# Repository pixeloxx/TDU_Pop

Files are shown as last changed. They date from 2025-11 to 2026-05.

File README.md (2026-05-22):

## Tactile Pop

A simple oral electro tactile interface based on this [paper by Kurt Kaczmarek](https://www.sciencedirect.com/science/article/pii/S1026309811001702) and some inspiration from Cthulhu Shield by [Sapien LLC](http://sapienllc.com/). 

The basic setup is a shield for the Arduino Mega board, with an edge connector for attaching TDU electrodes. The Tactile Pop itself uses a PCB, so it is not certified for contact with the mouth: please use it at your own risk! The pop should be coated with a food safe resin, leaving the electrodes exposed. Use gold coating on the electrode PCB for a safer surface coating. 

This repository contains firmware, patterns and Eagle project files for the Tactile Pop TDU. 

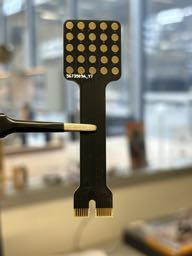
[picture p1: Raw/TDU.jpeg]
Tactile Display Unit (TDU)


Repository layout
----------------
- `Code/` — Arduino sketches and supporting code.
  - `Patterns/` — pattern generator and example patterns (`Patterns.ino`).
  - `Screen/`, `Serial/` — alternative sketches and helpers for serial interface and an attached display. 
- `Electronics/` — Eagle project files and CAM outputs for the controller shield and the the pop TDU pcb. 

Quick start
-----------
1. Open the relevant Arduino sketch from `Code/` in the Arduino IDE .
2. Compile and upload to your compatible microcontroller.
3. Use the `Patterns` sketch or the serial interface to send patterns to the device.

Electrode stimulation 
----------------------

A number of parameters in the pulse patter can be changed, to give a range of intensity and qualities of sensation. Longer pulses will effect Nociceptors (prickly, needle like sensations), while shorter will tend to activate tactile receptors. Some stimulation of taste receptors is also possible.     

The the following parameters can be edited, and fine tuned for each individual electrode. 

PP[] — Pulse Period (microseconds). Total period of one inner pulse (high + low). Unit: µs.
Pp[] — Pulse-on time (microseconds). Time the pin is HIGH during one inner pulse. Unit: µs. 
IN[] — Inner burst count (integer). Number of inner pulses in one inner burst. 
IP[] — Inner burst pause (microseconds). Pause after each inner burst (time between inner bursts). 
ON[] — Outer burst count (integer). Number of inner bursts in one outer burst. 

Sensing Tongue Contact
----------------------

It's possible to sense tongue contact using ADC-capable pins, which is only the first three rows of the TDU. 
 
 ```C#
    const int sensingPins[5][5] = {
      {A1, A2, A3, A4, A5},
      {A6, A7, A8, A9, A10},
      {A11, A12, A13, A14, A15},
      {1, 2, 3, 4, 5},
      {6, 7, 8, 9, 10}
    };
 ```

The example below shows how you can also read a chanel, to check if the tongue is in contact with an electrode.  
 ```C#
    
    int baseLine = 800; 

    bool readSensing(int row, int col) {
      if (row < 0 || row >= 5 || col < 0 || col >= 5) return -1;
      int pin = sensingPins[row][col];
      return analogRead(pin);
        pinMode(pin, OUTPUT);
        digitalWrite(pin, HIGH);
        delayMicroseconds(400);
        pinMode(pin, INPUT);
        int response = analogRead(pin);
        delay(IntensityDelay);
        pinMode(pin, OUTPUT);
        digitalWrite(pin, LOW);
        return (response>baseLine);
    }

 ```

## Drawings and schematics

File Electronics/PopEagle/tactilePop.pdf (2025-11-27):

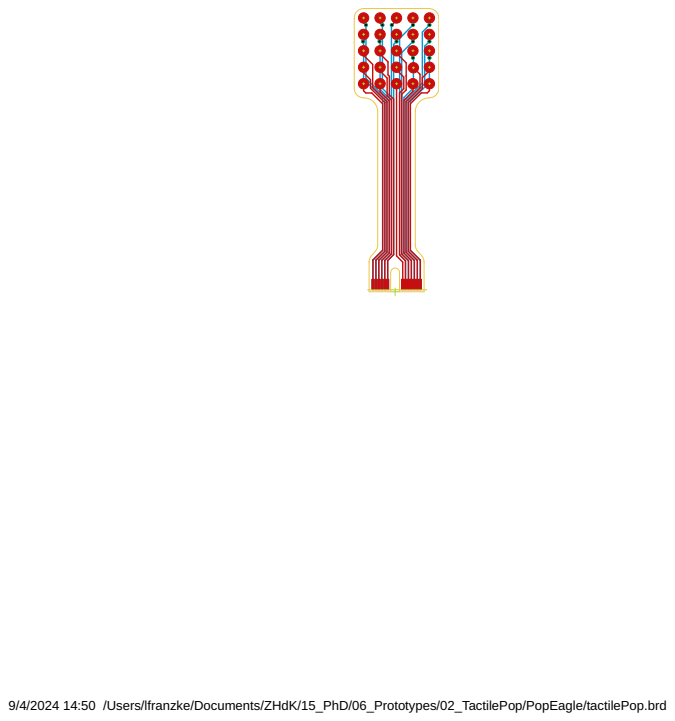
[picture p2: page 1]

9/4/2024 14:50 /Users/lfranzke/Documents/ZHdK/15_PhD/06_Prototypes/02_TactilePop/PopEagle/tactilePop.brd

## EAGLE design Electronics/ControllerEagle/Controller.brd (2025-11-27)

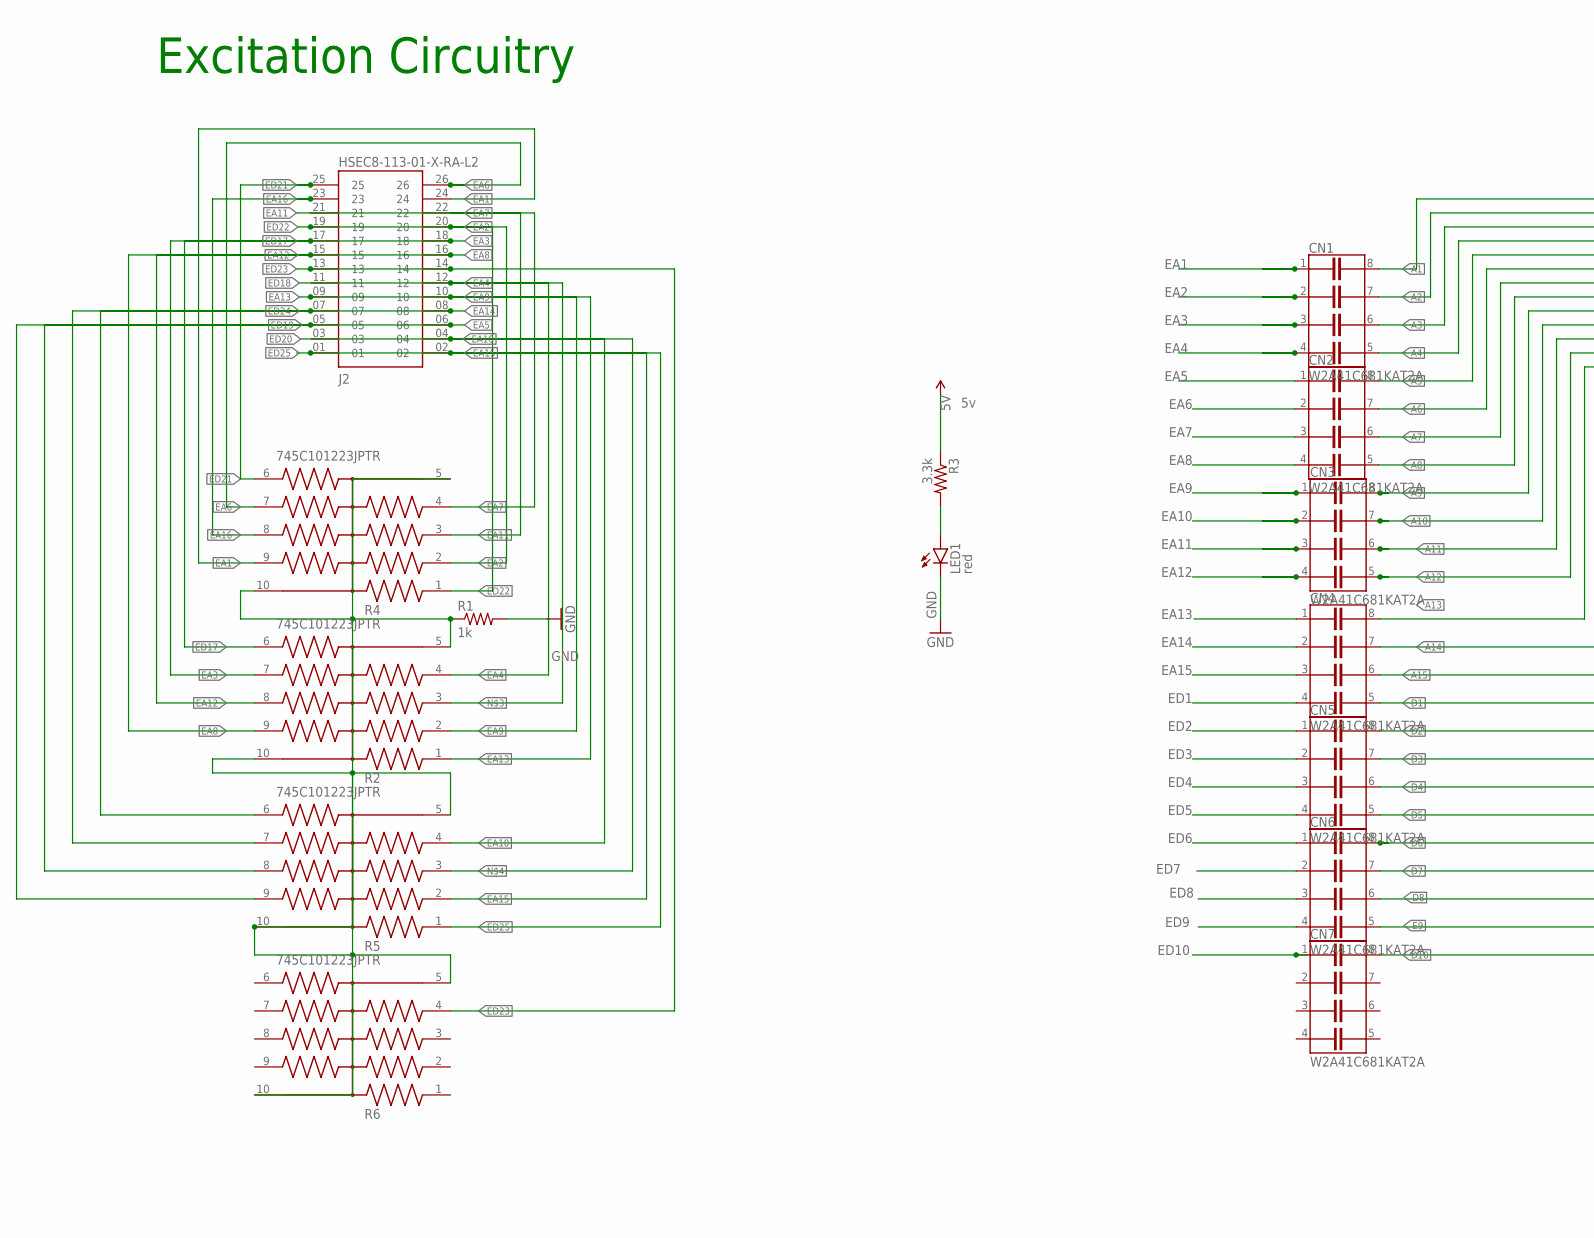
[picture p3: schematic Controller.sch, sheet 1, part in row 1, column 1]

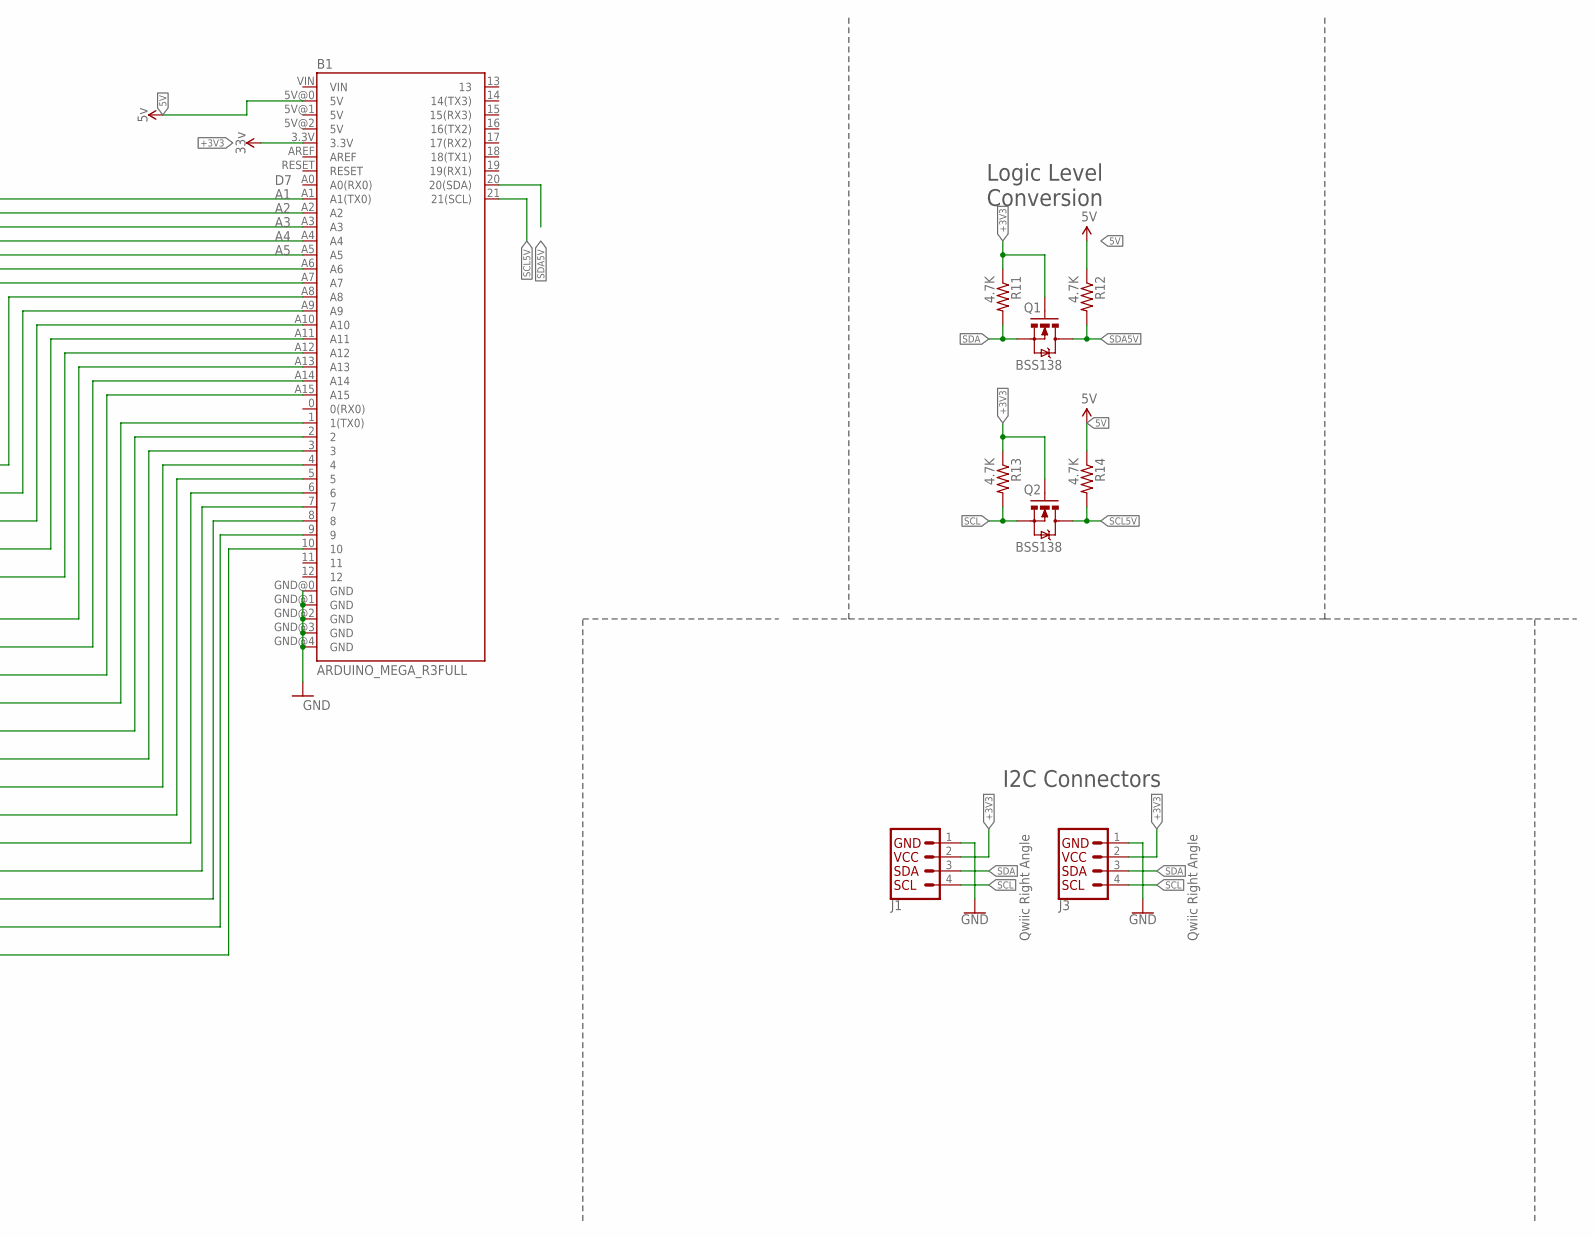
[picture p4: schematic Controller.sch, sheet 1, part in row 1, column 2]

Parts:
B1: ARDUINO_MEGA_R3FULL; ARDUINO_MEGA
CN1, CN2, CN3, CN4, CN5, CN6, CN7: W2A41C681KAT2A; CAPCAXE50P210X130X94-8N
J1, J3: Qwiic Right Angle; 1X04_1MM_RA
J2: HSEC8-113-01-X-RA-L2; SAMTEC_HSEC8-113-01-X-RA-L2
LED1: red; LED-1206
Q1, Q2: BSS138; SOT23-3
R1: 1k; 0402
R2, R4, R5, R6: 745C101223JPTR; RESCAV127P640X310X70-10N
R3: 3.3k; 0402
R11, R12, R13, R14: 4.7K; 0603-RES

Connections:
5V: B1.5V@0 (5V), R3.1, R12.1, R14.1
+3V3: B1.3.3V, J1.2, J3.2, Q1.1 (G), Q2.1 (G), R11.1, R13.1
A1: B1.A1 (A1(TX0)), CN1.8
A2: B1.A2, CN1.7
A3: B1.A3, CN1.6
A4: B1.A4, CN1.5
A5: B1.A5, CN2.8
A6: B1.A6, CN2.7
A7: B1.A7, CN2.6
A8: B1.A8, CN2.5
A9: B1.A9, CN3.8
A10: B1.A10, CN3.7
A11: B1.A11, CN3.6
A12: B1.A12, CN3.5
A13: B1.A13, CN4.8
A14: B1.A14, CN4.7
A15: B1.A15, CN4.6
D1: B1.1 (1(TX0)), CN4.5
D2: B1.2, CN5.8
D3: B1.3, CN5.7
D4: B1.4, CN5.6
D5: B1.5, CN5.5
D6: B1.6, CN6.8
D7: B1.7, CN6.7
D8: B1.8, CN6.6
D10: B1.10, CN7.8
E9: B1.9, CN6.5
EA1: CN1.1, J2.24, R4.9
EA2: CN1.2, J2.20, R4.2
EA3: CN1.3, J2.18, R2.7
EA4: CN1.4, J2.12, R2.4
EA5: CN2.1, J2.06, R5.9
EA6: CN2.2, J2.26, R4.7
EA7: CN2.3, J2.22, R4.4
EA8: CN2.4, J2.16, R2.9
EA9: CN3.1, J2.10, R2.2
EA10: CN3.2, J2.04, R5.4
EA11: CN3.3, J2.21, R4.3
EA12: CN3.4, J2.15, R2.8
EA13: CN4.1, J2.09, R2.1
EA14: CN4.2, J2.08, R5.7
EA15: CN4.3, J2.02, R5.2
EA16: J2.23, R4.8
ED1: CN4.4
ED2: CN5.1
ED3: CN5.2
ED4: CN5.3
ED5: CN5.4
ED6: CN6.1
ED7: CN6.2
ED8: CN6.3
ED9: CN6.4
ED10: CN7.1
ED17: J2.17, R2.6
ED19: J2.05, R5.8
ED21: J2.25, R4.6
ED22: J2.19, R4.1
ED23: J2.13, J2.14, R6.4
ED24: J2.07, R5.6
ED25: J2.01, R5.1
GND: B1.GND@0 (GND), B1.GND@1 (GND), B1.GND@2 (GND), B1.GND@3 (GND), B1.GND@4 (GND), J1.1, J3.1, LED1.C, R1.2
unnamed: LED1.A, R3.2
unnamed: R1.1, R2.5, R2.10, R4.5, R4.10, R5.5, R5.10, R6.5, R6.10
unnamed: J2.11, R2.3
unnamed: J2.03, R5.3
SCL: J1.4, J3.4, Q2.2 (S), R13.2
SCL5V: B1.21 (21(SCL)), Q2.3 (D), R14.2
SDA: J1.3, J3.3, Q1.2 (S), R11.2
SDA5V: B1.20 (20(SDA)), Q1.3 (D), R12.2

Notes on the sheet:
Excitation Circuitry
Logic Level Conversion
I2C Connectors

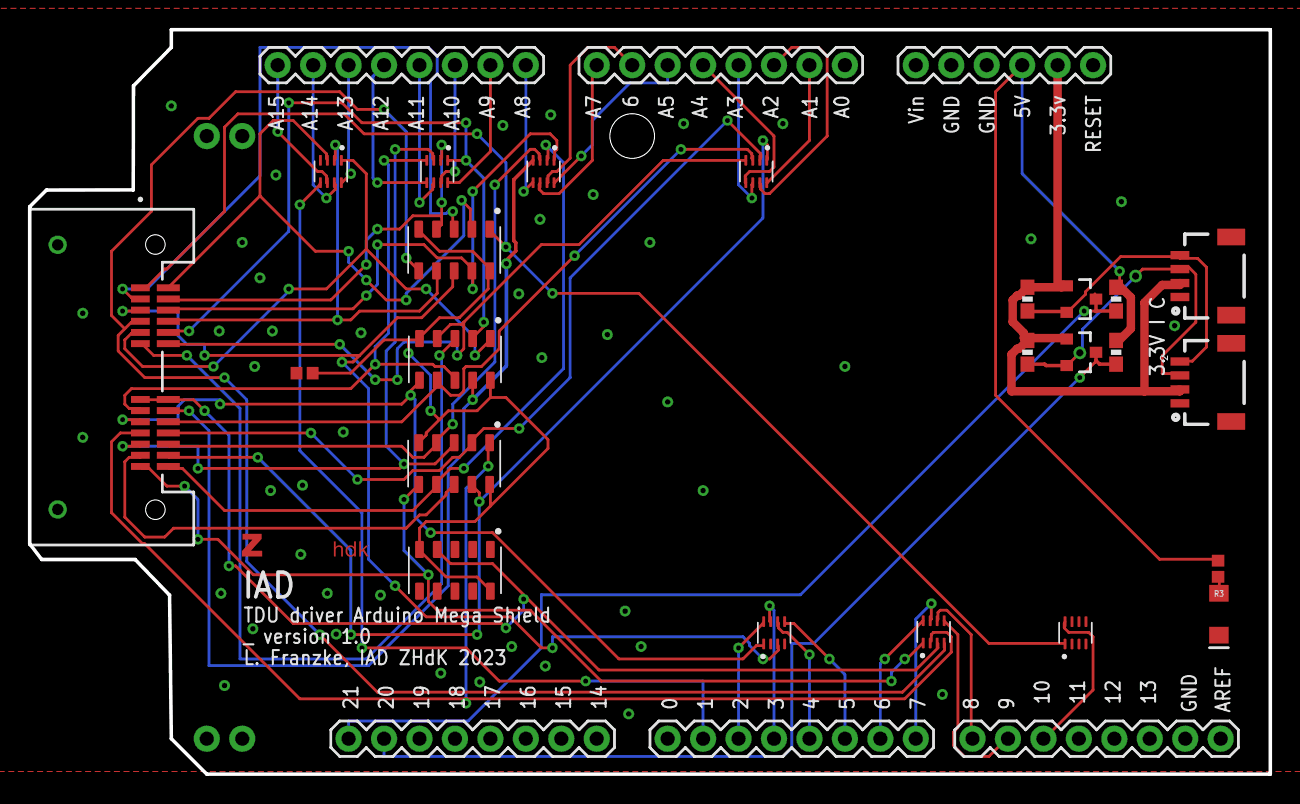
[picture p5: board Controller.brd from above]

Board: 2 copper layers, 88.9 x 53.3 mm, 25 parts (0 on the bottom side), 59 nets.

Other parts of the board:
U$1: ZHDK_LOGO

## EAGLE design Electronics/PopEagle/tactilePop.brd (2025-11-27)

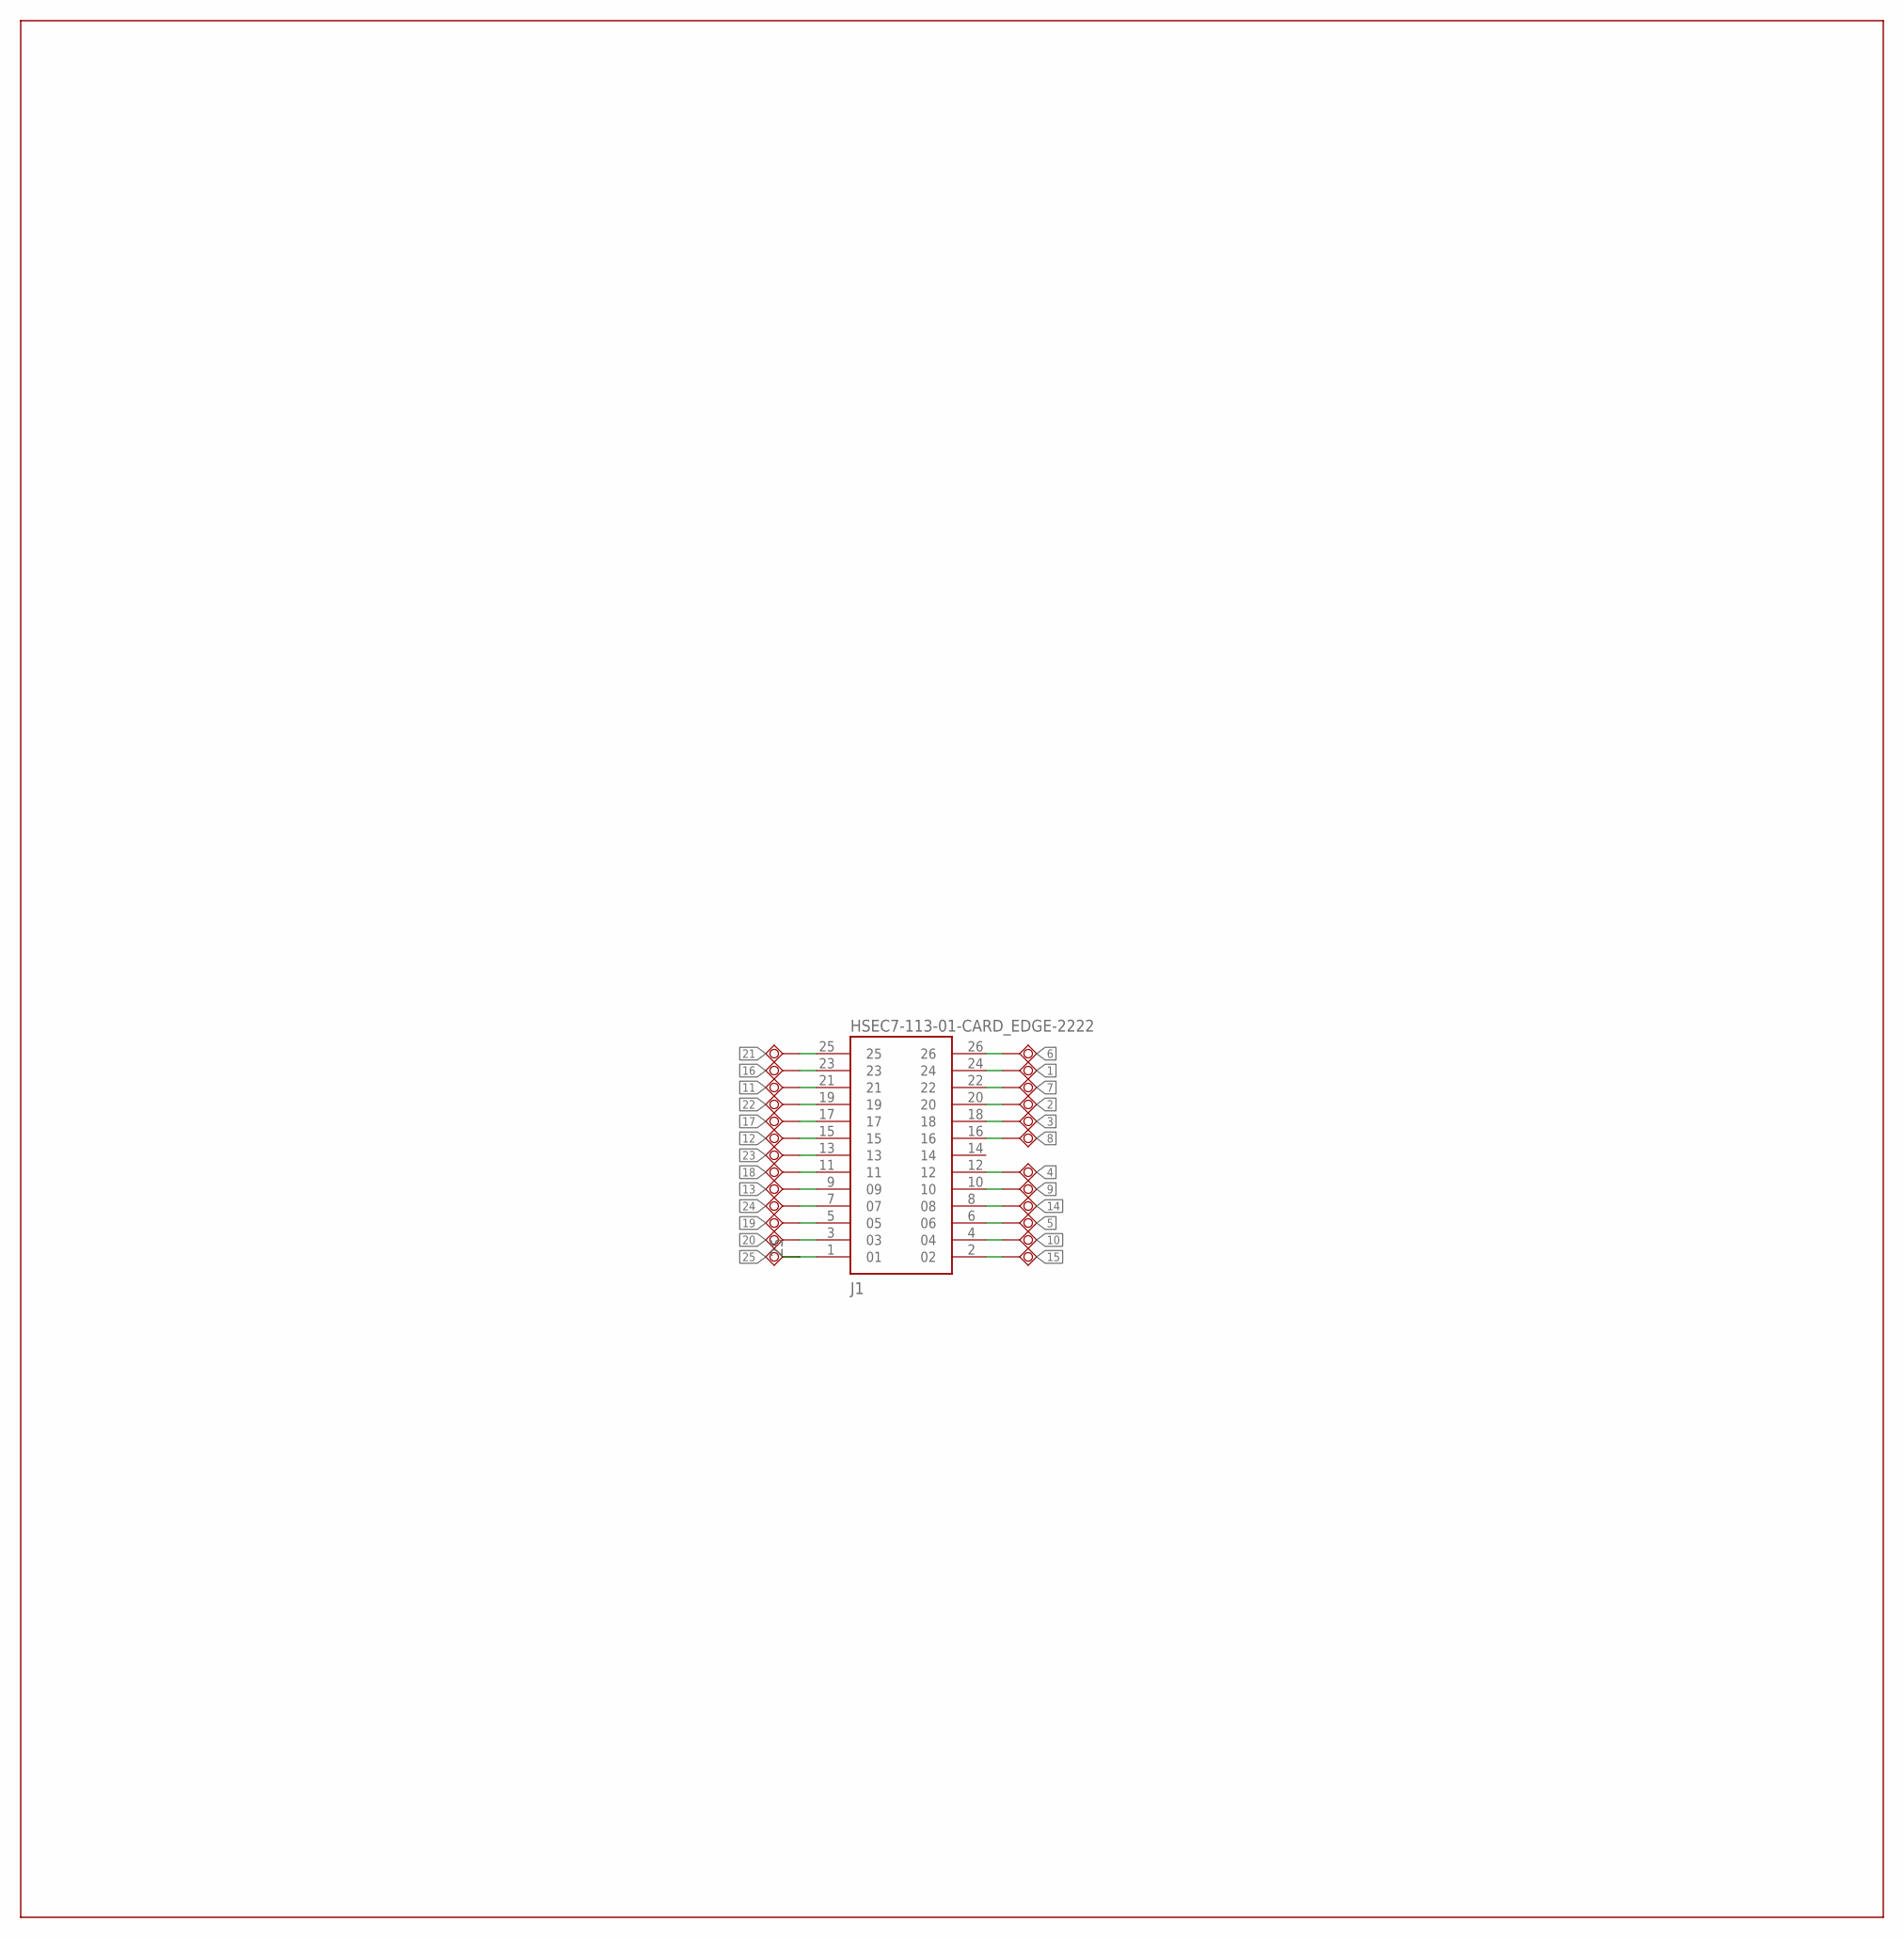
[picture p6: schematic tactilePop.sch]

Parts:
1, 2, 3: TESTPAD_TPSQB2,54; TESTPAD_B2,54
J1: HSEC7-113-01-CARD_EDGE-2222; HSEC8-113-01-X-RA-L2
TP1, TP3, TP6, TP7, TP8, TP9, TP10, TP11, TP12, TP13, TP14, TP15, TP16, TP17, TP18, TP19, TP20, TP21, TP22, TP23, TP24, TP25: TESTPAD_TPSQB2,54; TESTPAD_B2,54

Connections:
1: 1.TP, J1.24
2: 2.TP, J1.20
3: 3.TP, J1.18
4: J1.12, TP7.TP
5: J1.6, TP19.TP
6: J1.26, TP1.TP
7: J1.22, TP3.TP
8: J1.16, TP6.TP
9: J1.10, TP8.TP
10: J1.4, TP10.TP
11: J1.21, TP24.TP
12: J1.15, TP21.TP
13: J1.9, TP16.TP
14: J1.8, TP20.TP
15: J1.2, TP11.TP
16: J1.23, TP25.TP
17: J1.17, TP22.TP
18: J1.11, TP17.TP
19: J1.5, TP14.TP
20: J1.3, TP13.TP
21: J1.25, TP9.TP
22: J1.19, TP23.TP
23: J1.13, TP18.TP
24: J1.7, TP15.TP
25: J1.1, TP12.TP

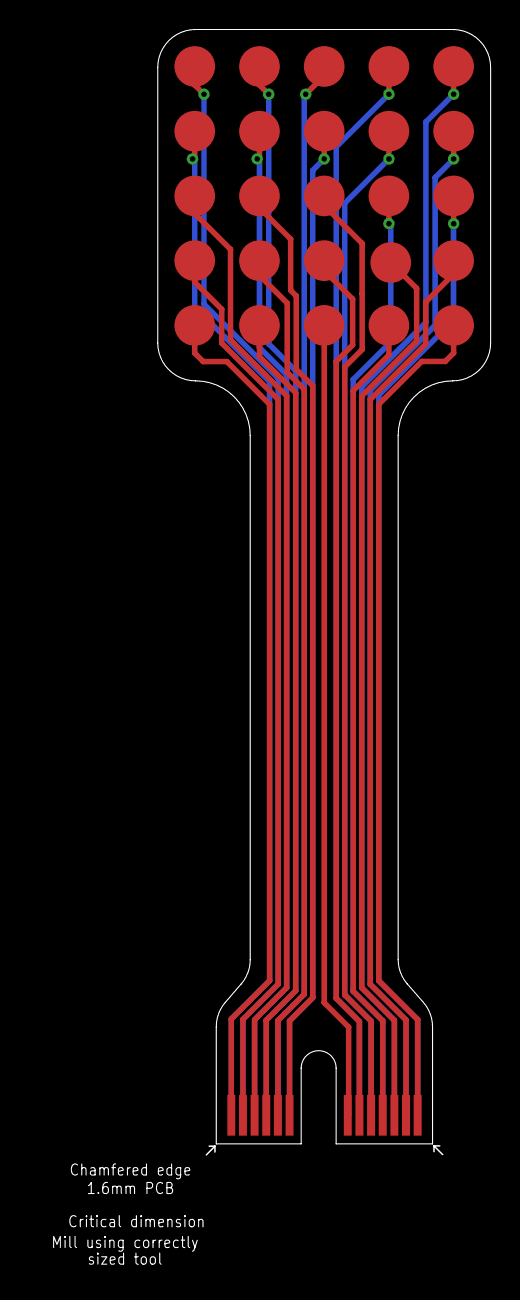
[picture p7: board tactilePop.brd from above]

Board: 2 copper layers, 22.9 x 77.3 mm, 26 parts (0 on the bottom side), 25 nets.

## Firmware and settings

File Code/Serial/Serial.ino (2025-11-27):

#include "TDU.h"

#define HighPeriod 400
#define LowPeriod 400
#define midDelay 1000
#define midDelay 1000
#define IntensityDelay 10 // adjust this to adjust intensity of tactile buttons.

#define serialSendDelay 20

long lastSerialSendTime = 0;

int _PinMap[5][5] = {
    {A1, A2, A3, A4, A5},
    {A6, A7, A8, A9, A10},
    {A11, A12, A13, A14, A15},
    {1, 2, 3, 4, 5},
    {6, 7, 8, 9, 10}};

/*
  A simple demonstration of Tongue Display Unit with basic patterns
*/

int array[MegaShield_CHANNELS];

// two arrays I used to generate geometric patterns

int cElectrodeMap[5][5] = {
    {0, 1, 2, 4, 5},
    {6, 7, 8, 9, 10},
    {11, 12, 13, 14, 15},
    {16, 17, 18, 19, 20},
    {21, 22, 23, 24, 25}};

int on[5][5] = {
    {0, 0, 0, 0, 0},
    {0, 0, 0, 0, 0},
    {0, 0, 0, 0, 0},
    {0, 0, 0, 0, 0},
    {0, 0, 0, 0, 0}};
int active[5][5] = {
    {0, 0, 0, 0, 0},
    {0, 0, 0, 0, 0},
    {0, 0, 0, 0, 0},
    {0, 0, 0, 0, 0},
    {0, 0, 0, 0, 0}};

// reverse lookup for electrode index -> row/col
int indexRow[MegaShield_CHANNELS];
int indexCol[MegaShield_CHANNELS];

void buildReverseMap()
{
  for (int k = 0; k < MegaShield_CHANNELS; k++)
  {
    indexRow[k] = -1;
    indexCol[k] = -1;
  }
  for (int r = 0; r < 5; r++)
  {
    for (int c = 0; c < 5; c++)
    {
      int idx = cElectrodeMap[r][c];
      if (idx >= 0 && idx < MegaShield_CHANNELS)
      {
        indexRow[idx] = r;
        indexCol[idx] = c;
      }
    }
  }
}

// these are waveform parameter as described by Kurt Kaczmarek here https://www.sciencedirect.com/science/article/pii/S10MegaShield_CHANNELS309811001702
// than can be changed to create a large range of sensations on the tongue.
int PP[] = {57, 57, 57, 57, 57, 57, 57, 57, 57, 57, 57, 57, 57, 57, 57, 57, 57, 57, 57, 57, 57, 57, 57, 57, 57, 57};
int Pp[] = {57, 57, 57, 57, 57, 57, 57, 57, 57, 57, 57, 57, 57, 57, 57, 57, 57, 57, 57, 57, 57, 57, 57, 57, 57, 57};
int IN[] = {3, 3, 3, 3, 3, 3, 3, 3, 3, 3, 3, 3, 3, 3, 3, 3, 3, 3, 3, 3, 3, 3, 3, 3, 3, 3};
int IP[] = {150, 150, 150, 150, 150, 150, 150, 150, 150, 150, 150, 150, 150, 150, 150, 150, 150, 150, 150, 150, 150, 150, 150, 150, 150, 150};
int ON[] = {5, 5, 5, 5, 5, 5, 5, 5, 5, 5, 5, 5, 5, 5, 5, 5, 5, 5, 5, 5, 5, 5, 5, 5, 5, 5};
TDU mytdu; // creating an instance of TDU

// a function to update geometric patterns in the demo at the beginning of the program
void updatepattern(int input[5][5])
{

  // if the On array is ative, set the corresponding electrode active.
  for (int j = 0; j < 5; j++)
  {
    for (int i = 0; i < 5; i++)
    {
      array[cElectrodeMap[i][j]] = input[i][j];
    }
  }
}

void resetParams()
{
  // assign default waveform parameters element-wise
  for (int i = 0; i < MegaShield_CHANNELS; i++)
  {
    PP[i] = 57;
    Pp[i] = 57;
    IN[i] = 3;
    IP[i] = 150;
    ON[i] = 5;
  }
}
void clearPattern()
{
  for (int i = 0; i < 5; i++)
  {
    for (int j = 0; j < 5; j++)
    {
      on[i][j] = 0;
    }
  }
}

void printArrayCSV(const uint16_t *arr, size_t n)
{
  for (size_t i = 0; i < n; ++i)
  {
    Serial.print(arr[i]);
    if (i + 1 < n)
      Serial.print(','); // comma between values
  }
  Serial.println(); // newline after the line
}

void sensorsToSerial(int sensorCount = MegaShield_CHANNELS)
{

  uint16_t sensors[sensorCount] = {0};

  if (sensorCount <= 0)
    sensorCount = MegaShield_CHANNELS;
  if (sensorCount > MegaShield_CHANNELS)
    sensorCount = MegaShield_CHANNELS;

  // drive the first sensorCount pins HIGH (row-major)
  int idx = 0;
  for (int i = 0; i < 5 && idx < sensorCount; i++)
  {
    for (int j = 0; j < 5 && idx < sensorCount; j++)
    {
      pinMode(_PinMap[i][j], OUTPUT);
      digitalWrite(_PinMap[i][j], HIGH);
      idx++;
    }
  }

  delayMicroseconds(HighPeriod); // positive pulse

  // read back the values into sensors[0..sensorCount-1]
  idx = 0;
  for (int i = 0; i < 5 && idx < sensorCount; i++)
  {
    for (int j = 0; j < 5 && idx < sensorCount; j++)
    {
      pinMode(_PinMap[i][j], INPUT);
      sensors[idx] = floor((uint16_t)analogRead(_PinMap[i][j])/100);
      idx++;
    }
  }

  delay(IntensityDelay);

  // restore the driven pins to LOW output for the first sensorCount pins
  idx = 0;
  for (int i = 0; i < 5 && idx < sensorCount; i++)
  {
    for (int j = 0; j < 5 && idx < sensorCount; j++)
    {
      pinMode(_PinMap[i][j], OUTPUT);
      digitalWrite(_PinMap[i][j], LOW);
      idx++;
    }
  }

  delayMicroseconds(LowPeriod); // negative pulse
  delay(1);

  // print only the elements we read
  printArrayCSV(sensors, sensorCount);
}

void applyStimulus()
{
  updatepattern(active);
  mytdu.UpdateStimuli(array, PP, Pp, IN, IP, ON);

  for (int k = 0; k < 3; k++)
  {
    mytdu.Stimulate();
  }

  updatepattern(on);
  mytdu.UpdateStimuli(array, PP, Pp, IN, IP, ON);
}

// read a line of comma-separated uint16_t values from Serial and use them to set on[][]
void readSerialAndApply()
{
  if (!Serial.available())
    return;

  String line = Serial.readStringUntil('\n');
  line.trim();
  if (line.length() == 0)
    return;

  // parse tokens as strict binary values (0 or 1) separated by commas
  const int maxTokens = MegaShield_CHANNELS;
  uint8_t values[maxTokens];
  int count = 0;

  char buf[256];
  line.toCharArray(buf, sizeof(buf));
  char *tok = strtok(buf, ",");
  while (tok != NULL && count < maxTokens)
  {
    // skip leading whitespace
    char *p = tok;
    while (*p == ' ' || *p == '\t' || *p == '\r' || *p == '\n')
      p++;

    // accept only '0' or '1' as valid token start. Ignore invalid tokens.
    if (*p == '0')
    {
      values[count++] = 0;
    }
    else if (*p == '1')
    {
      values[count++] = 1;
    }
    // otherwise token is ignored

    tok = strtok(NULL, ",");
  }

  // clear previous pattern
  for (int r = 0; r < 5; r++)
    for (int c = 0; c < 5; c++)
      active[r][c] = 0;

  // apply parsed binary values to electrodes 0..count-1 using reverse map
  for (int i = 0; i < count; i++)
  {
    int r = indexRow[i];
    int c = indexCol[i];
    if (r >= 0 && c >= 0)
    {
      active[r][c] = values[i] ? 1 : 0;
      Serial.print(active[r][c]);
    }
  }
  Serial.println();
  // printArrayCSV(sensors, sensorCount);
}

void setup()
{
  mytdu.Begin();
  buildReverseMap();
  Serial.begin(115200);
  Serial.println("Pattern Demonstration begin...");
}

void loop()
{
  // activate patterns, based on patern provided over serial.
  // handle reading values.

  readSerialAndApply();
  applyStimulus();

  if (lastSerialSendTime <= millis() - serialSendDelay)
  {
    sensorsToSerial(7); // only read the first 7 sensors
    lastSerialSendTime = millis();
  }
}

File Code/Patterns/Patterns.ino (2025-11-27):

#include "TDU.h"

/*
  A simple demonstration of Tongue Display Unit with basic patterns
*/

int array[MegaShield_CHANNELS];

// two arrays I used to generate geometric patterns

int cElectrodeMap[5][5] = {
    {0, 1, 2, 4, 5},
    {6, 7, 8, 9, 10},
    {11, 12, 13, 14, 15},
    {16, 17, 18, 19, 20},
    {21, 22, 23, 24, 25}};

int on[5][5] = {
    {0, 0, 0, 0, 0},
    {0, 0, 0, 0, 0},
    {0, 0, 0, 0, 0},
    {0, 0, 0, 0, 0},
    {0, 0, 0, 0, 0}};

int active[5][5] = {
    {0, 0, 0, 0, 0},
    {0, 0, 0, 0, 0},
    {0, 0, 0, 0, 0},
    {0, 0, 0, 0, 0},
    {0, 0, 0, 0, 0}};

// these are waveform parameter as described by Kurt Kaczmarek here https://www.sciencedirect.com/science/article/pii/S10MegaShield_CHANNELS309811001702
// than can be changed to create a large range of sensations on the tongue.
int PP[] = {57, 57, 57, 57, 57, 57, 57, 57, 57, 57, 57, 57, 57, 57, 57, 57, 57, 57, 57, 57, 57, 57, 57, 57, 57, 57};
int Pp[] = {57, 57, 57, 57, 57, 57, 57, 57, 57, 57, 57, 57, 57, 57, 57, 57, 57, 57, 57, 57, 57, 57, 57, 57, 57, 57};
int IN[] = {3, 3, 3, 3, 3, 3, 3, 3, 3, 3, 3, 3, 3, 3, 3, 3, 3, 3, 3, 3, 3, 3, 3, 3, 3, 3};
int IP[] = {150, 150, 150, 150, 150, 150, 150, 150, 150, 150, 150, 150, 150, 150, 150, 150, 150, 150, 150, 150, 150, 150, 150, 150, 150, 150};
int ON[] = {5, 5, 5, 5, 5, 5, 5, 5, 5, 5, 5, 5, 5, 5, 5, 5, 5, 5, 5, 5, 5, 5, 5, 5, 5, 5};
TDU mytdu; // creating an instance of TDU

// a function to update geometric patterns in the demo at the beginning of the program
void updatepattern()
{

  // if the On array is ative, set the corresponding electrode active.
  for (int j = 0; j < 5; j++)
  {
    for (int i = 0; i < 5; i++)
    {
      array[cElectrodeMap[i][j]] = on[i][j];
    }
  }
}

void resetParams()
{
  // assign default waveform parameters element-wise
  for (int i = 0; i < MegaShield_CHANNELS; i++)
  {
    PP[i] = 57;
    Pp[i] = 57;
    IN[i] = 3;
    IP[i] = 150;
    ON[i] = 5;
  }
}
void clearPattern()
{
  for (int i = 0; i < 5; i++)
  {
    for (int j = 0; j < 5; j++)
    {
      on[i][j] = 0;
    }
  }
}
// a demonstration of geometric patterns (lines, sweeps, pulsing X's
void demonstration()
{
  resetParams();
  // lines top to bottom 5x
  for (int m = 0; m < 5; m++)
  {
    Serial.println("Sweeping lines top to bottom.");
    for (int i = 0; i < 5; i++)
    {
      on[i][0] = 1;
      on[i][1] = 1;
      on[i][2] = 1;
      on[i][3] = 1;
      on[i][4] = 1;
      updatepattern();

      mytdu.UpdateStimuli(array, PP, Pp, IN, IP, ON);

      for (int k = 0; k < 3; k++)
      {
        mytdu.Stimulate();
      }
      Serial.println("check 3");
      on[i][0] = 0;
      on[i][1] = 0;
      on[i][2] = 0;
      on[i][3] = 0;
      on[i][4] = 0;
      updatepattern();
      mytdu.UpdateStimuli(array, PP, Pp, IN, IP, ON);
    }
  }

  // lines left to right 5x
  for (int m = 0; m < 5; m++)
  {
    Serial.println("Sweeping lines left to right.");
    for (int i = 0; i < 5; i++)
    {
      on[0][i] = 1;
      on[1][i] = 1;
      on[2][i] = 1;
      on[3][i] = 1;
      on[4][i] = 1;
      updatepattern();
      mytdu.UpdateStimuli(array, PP, Pp, IN, IP, ON);
      for (int k = 0; k < 3; k++)
      {
        mytdu.Stimulate();
      }
      on[0][i] = 0;
      on[1][i] = 0;
      on[2][i] = 0;
      on[3][i] = 0;
      on[4][i] = 0;
      updatepattern();
      mytdu.UpdateStimuli(array, PP, Pp, IN, IP, ON);
    }
  }

  clearPattern();
  // single points left to right

  for (int i = 0; i < MegaShield_CHANNELS; i++)
  {
    ON[i] = 5;
  }

  for (int index = 0; index < MegaShield_CHANNELS; index++)
  {
    // one by one, set each electrode active
    clearPattern();
    int x = index / 5;
    int y = index % 5;
    on[x][y] = 1;

    for (int m = 0; m < 5; m++)
    {
      Serial.print("single point");
      Serial.println(index);
      mytdu.UpdateStimuli(array, PP, Pp, IN, IP, ON);
      for (int k = 0; k < 6; k++)
      {
        mytdu.Stimulate();
      }
    }

    updatepattern();
    mytdu.UpdateStimuli(array, PP, Pp, IN, IP, ON);
  }

  for (int i = 0; i < MegaShield_CHANNELS; i++)
  {
    ON[i] = 5;
  }

  // Pulsing X 5x
  on[1][0] = 1;
  on[2][1] = 1;
  on[3][2] = 1;
  on[4][3] = 1;
  on[4][0] = 1;
  on[3][1] = 1;
  on[2][2] = 1;
  on[1][3] = 1;
  updatepattern();
  for (int m = 0; m < 5; m++)
  {
    Serial.println("Pulsing 'X' with varying intensity.");
    for (int i = 1; i < 50; i++)
    {
      for (int x = 0; x < MegaShield_CHANNELS; x++)
      {
        Pp[x] = i + 7;
        PP[x] = i + 8;
        ON[x] = (i + 10) / 10;
        IP[x] = 100 + i;
      }
      mytdu.UpdateStimuli(array, PP, Pp, IN, IP, ON);
      for (int k = 0; k < 1; k++)
      {
        mytdu.Stimulate();
      }
    }
  }
  for (int x = 0; x < MegaShield_CHANNELS; x++)
  {
    Pp[x] = 9;
  }
  on[1][0] = 0;
  on[2][1] = 0;
  on[3][2] = 0;
  on[4][3] = 0;
  on[4][4] = 0;
  on[4][0] = 0;
  on[3][1] = 0;
  on[2][2] = 0;
  on[1][3] = 0;
  on[0][4] = 0;
  updatepattern();
  mytdu.UpdateStimuli(array, PP, Pp, IN, IP, ON);
}

void setup()
{
  mytdu.Begin();
  Serial.begin(9600);
  delay(1000);
  Serial.println("sizeof(Pp): ");
  Serial.println(sizeof(Pp) / sizeof(Pp[0]));
  Serial.println("sizeof(ON): ");
  Serial.println(sizeof(ON) / sizeof(ON[0]));
  Serial.println("sizeof(PP): ");
  Serial.println(sizeof(PP) / sizeof(PP[0]));
  Serial.println("sizeof(IN): ");
  Serial.println(sizeof(IN) / sizeof(IN[0]));
  Serial.println("sizeof(IP): ");
  Serial.println(sizeof(IP) / sizeof(IP[0]));
  Serial.println("Pattern Demonstration begin...");
  delay(1000);
}

void loop()
{
  // do nothing
  demonstration(); // run through demonstration once
}

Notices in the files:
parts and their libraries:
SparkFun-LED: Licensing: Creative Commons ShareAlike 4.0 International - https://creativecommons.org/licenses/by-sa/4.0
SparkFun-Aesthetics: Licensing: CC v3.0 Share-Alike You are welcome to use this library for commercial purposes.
